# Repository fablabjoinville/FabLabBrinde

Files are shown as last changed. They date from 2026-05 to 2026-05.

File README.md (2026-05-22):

# Lâmpada Relâmpago — Kit Comemorativo 10 Anos Fab Lab Joinville

Uma versão curta e alegre do projeto: uma nuvem, um relâmpago e um pouco de mágica magnética.
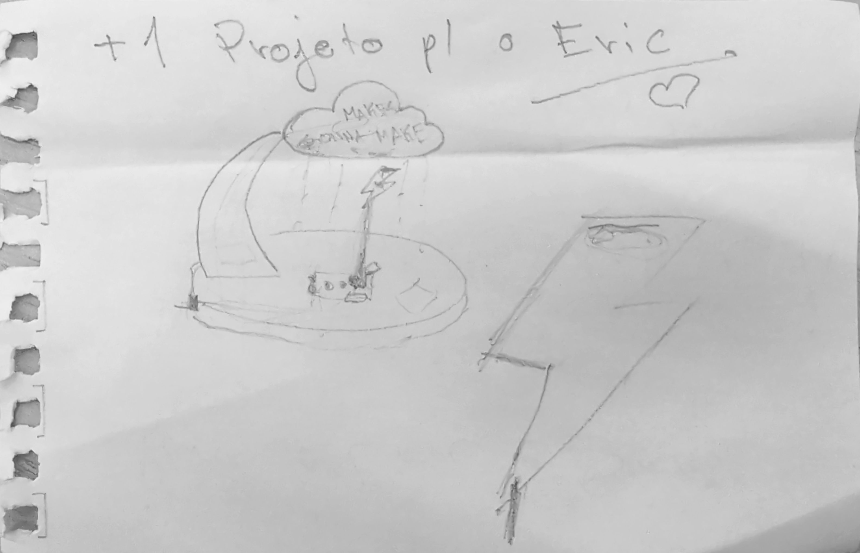
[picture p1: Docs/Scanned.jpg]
Esboço — eu e o Segui

_O esboço que eu e o Segui fizemos — foi assim que começou._

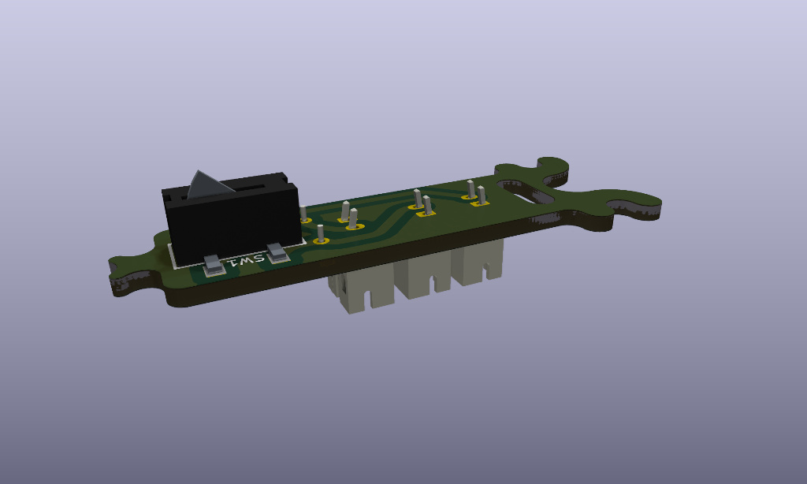
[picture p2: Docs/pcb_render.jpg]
Render da placa montada

Como funciona (resumo):

- Ímãs se atraem e puxam a peça móvel.
- A PCB flexiona e aciona o switch (click!).
- LEDs tipo "string" acendem, iluminando a nuvem e o relâmpago.
O que tem aqui:

- Arquivos KiCad e gerbers para a PCB
- Vetores CNC para a base
- Modelos 3D para nuvem e relâmpago
Dicas rápidas:

- Verifique a profundidade do alojamento do switch se não houver clique.
- Teste os LEDs antes da montagem final.

Contribuições e melhorias são bem-vindas — faça brilhar! ✨
Licença: open-source (maker-friendly).
# Lâmpada Relâmpago — Kit Comemorativo 10 Anos Fab Lab Joinville

Parabéns — você encontrou um pedaço do trovão! Este repositório guarda tudo que você precisa para fabricar e montar a lâmpada relâmpago do aniversário de 10 anos do Fab Lab Joinville. É um presente que brilha, faz "click" e pode provocar sorrisos.

## Imagens (porque todo projeto merece glamour)

- Esboço do conceito: ./Docs/Scanned.jpg
- Render da placa: ./Docs/pcb_render.jpg

## Em poucas palavras (sem jargões chatos)

Imagine uma nuvem fofinha que guarda um segredo elétrico e um relâmpago que, quando aproximado, faz a nuvem piscar como se tivesse contado uma piada muito boa. Dois ímãs se apaixonam, a placa dá um suspiro elástico, o interruptor faz "click" e os LEDs dançam em azul.

Como funciona, versão curta e dramática:

1. Os ímãs da nuvem e do relâmpago se atraem (romance magnético).
2. A PCB flexiona levemente e ativa o switch (o gran finale do drama).
3. LEDs tipo "string" acendem, iluminando a nuvem e o relâmpago.

## O que vem no kit (ou nesta pasta)

- Arquivos KiCad e gerbers para a placa (PCB).
- Vetores para CNC da base de madeira.
- Modelos 3D para impressão da nuvem e do relâmpago.
- Documentação e imagens no diretório `Docs`.

## Ferramentas e materiais (a lista do faz-tudo)

- Fresadora CNC (para a base)
- Impressora 3D (para as peças decorativas)
- Estação de solda e estanho
- Ímãs de neodímio (pequenos, mas poderosos)
- Fios e conector JST para alimentação
- LEDs tipo "string" (azuis recomendados)

## Montagem — passo a passo para heróis e heroínas

1. Fresagem da base: corte o alojamento para o switch com cuidado para permitir o clique quando a PCB flexiona.
2. Monte a PCB: solde o switch detector (KFC-V-105-2), o conector JST e os fios dos LEDs.
3. Prenda os ímãs: cole nos locais indicados na nuvem e no relâmpago. Verifique a polaridade — a atração é essencial.
4. Teste rápido: ligue os LEDs antes de montar tudo para garantir que a fiação está certa.
5. Montagem final: encaixe a PCB na base, coloque a nuvem por cima e passe o relâmpago pela abertura.
6. Aproxime o relâmpago da nuvem — e voilà, faça seu pedido (ou só admire a luz).

## Créditos e agradecimentos

Obrigado ao Fab Lab Joinville pela inspiração e por deixar a imaginação virar protótipo. Projeto colaborativo — contribuições são bem-vindas!

## Licença

Open-source e maker-friendly. Compartilhe, modifique e faça brilhar — com amor e responsabilidade.

— Equipe Fab Lab Joinville

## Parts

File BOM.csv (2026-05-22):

Referência | Descrição | Quantidade | Notas
PCB | Placa FabLaBrinde Customizada | 1 | Fibra de vidro 1.6mm
SW1 | Detector Switch KFC-V-105-2 | 1 | Montagem SMD/Invertida
LED1 | LED amarelo para diorama (3V) | 1 | Inserir dentro do raio
LED2 | String LED Azul (5V) | 1 | Inserir dentro da nuvem
R1 | Resistor 220Ω | 1 | Para limitar corrente do LED amarelo
MAG1, MAG2 | Ímã De Neodímio Quadrado De 20x4x2mm N42 | 2 | Atração entre nuvem e raio
BASE | Base de Madeira Fresada | 1 | Madeira de lei ou MDF
3D-NUVEM | Peça 3D - Nuvem | 1 | Material translúcido/branco
3D-RAIO | Peça 3D - Relâmpago | 1 | Material amarelo/sólido
JST1 | Conector JST XH 2.50mm Macho (Montado em PCB) | 3 | Para entrada e saída de energia
JST2 | Conector JST XH 2.50mm Femea (Crimpado em fio) | 3 | Para entrada e saída de energia
PAR1-4 | Parafusos M3x6mm | 10 | Fixação da PCB na base

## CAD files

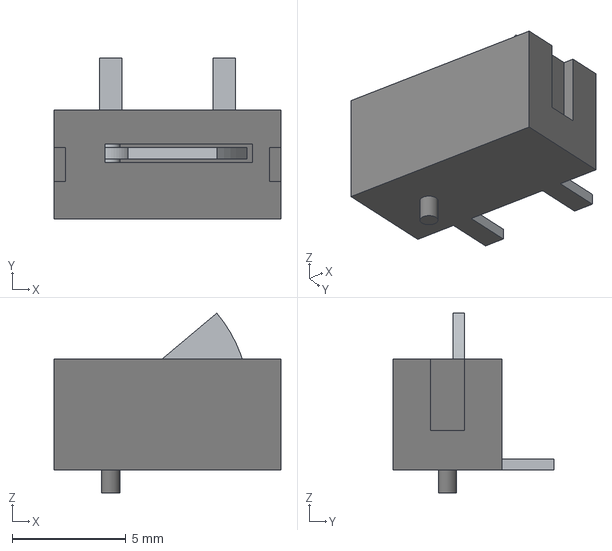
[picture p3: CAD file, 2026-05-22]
PCB/Switch.step
10.0 x 7.10 x 7.92 mm

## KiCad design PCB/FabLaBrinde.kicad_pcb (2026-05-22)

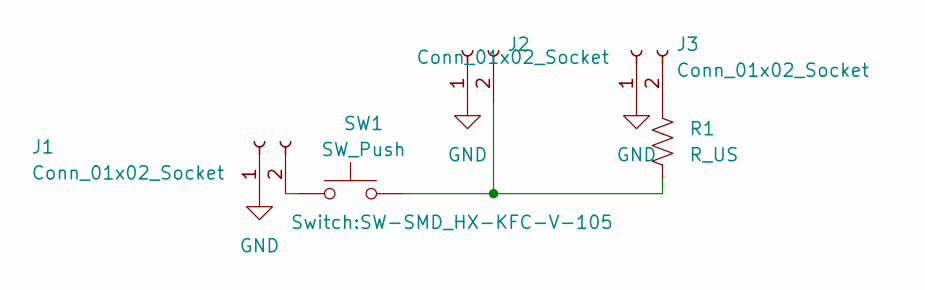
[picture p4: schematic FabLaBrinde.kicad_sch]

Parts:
J1, J2, J3: Conn_01x02_Socket; JST_PH_B2B-PH-K_1x02_P2.00mm_Vertical
R1: R_US; R_Axial_DIN0204_L3.6mm_D1.6mm_P5.08mm_Horizontal
SW1: SW_Push; SW-SMD_HX-KFC-V-105

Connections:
GND: J1.1, J2.1, J3.1
unnamed: J1.2, SW1.1
unnamed: J2.2, R1.2, SW1.2
unnamed: J3.2, R1.1

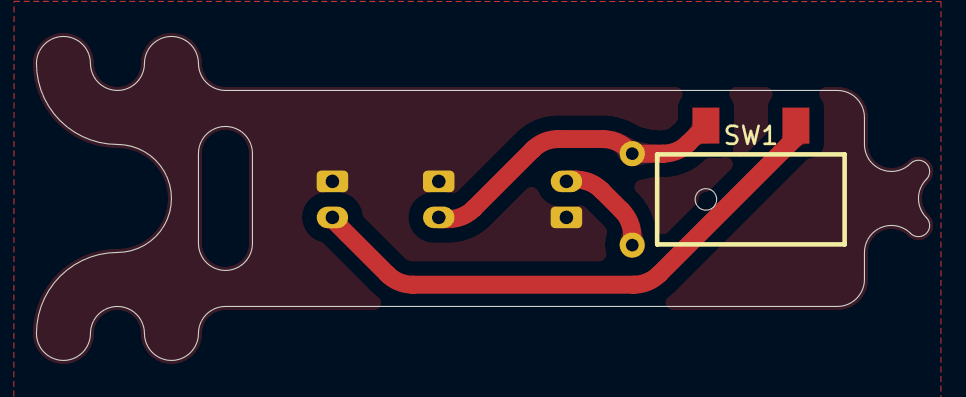
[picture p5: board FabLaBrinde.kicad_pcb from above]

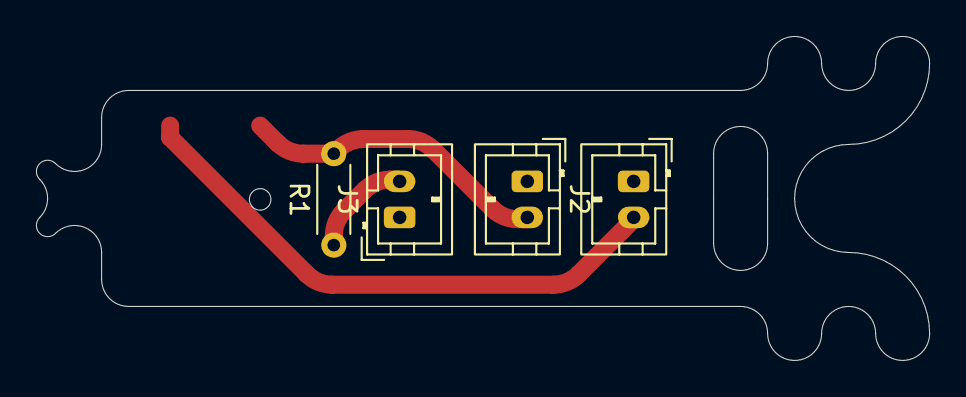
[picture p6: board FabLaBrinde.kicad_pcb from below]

Board: 2 copper layers, 49.6 x 18.0 mm, 5 parts (4 on the bottom side), 4 nets.

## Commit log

2026-05-22 Initial commit: BOM, PCB files, docs, and README
    [BOM.csv]
2026-05-22 Add KiCad PCB files and Gerbers directly to repository
    [FabLaBrinde-B_Cu.gbr, FabLaBrinde-B_Mask.gbr, FabLaBrinde-B_Paste.gbr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]
2026-05-22 Updt BOM
    [BOM.csv]
